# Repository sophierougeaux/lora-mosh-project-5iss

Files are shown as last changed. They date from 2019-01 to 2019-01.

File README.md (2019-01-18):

# LoRa Project: Smart Gas Sensor
> Elie Taillardat & Sophie Rougeaux

##### *Key-words:* ```Arduino``` ```KiCad``` ```The Thing Network``` ```LoRa``` ```Node-RED``` ```IoT``` ```Gas sensor```

This project is realised in the 5th year PTP ISS at INSA Toulouse.
A **LoRa-connected gas sensor** has been developed to alert the user about the concentration of health threatening gas near the sensor.

# Content

This repository contains :
- **KiCad PCB Files**: A shield for the gas sensor to plug on an Arduino Uno (made with [KiCad](http://kicad-pcb.org/))
- **Arduino Code**: The code for the microcontroler (using [Arduino IDE](https://www.arduino.cc/en/Main/Software))

A **Node-RED Dashboard** has been done to stay connected with your sensor. The development of this HMI is described at the end of this Readme. ([Node-RED](https://nodered.org/) and [Freeboard.io](https://freeboard.io/))

## KiCad PCB Files
### Overview
The shield is composed of :
- A home-made gas sensor (made at [AIME](https://www.aime-toulouse.fr/cmsms/index.php))
- An amplifier stage for home-made gas sensor
- A commercial gas sensor for the calibration of the home-made one (Grove connectors)
- A LoRa chip for the data transmission
- A LED as an on/off indicator

> We built our own footprints libraries expect for the Arduino Uno component

### Schematics

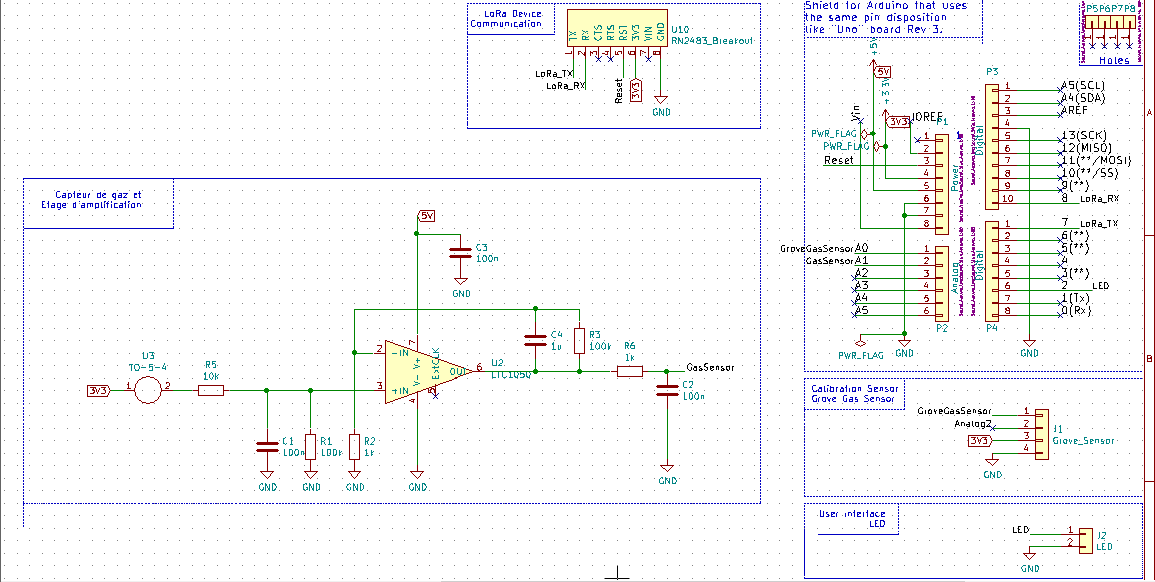
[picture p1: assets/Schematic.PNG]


### PCB Layout

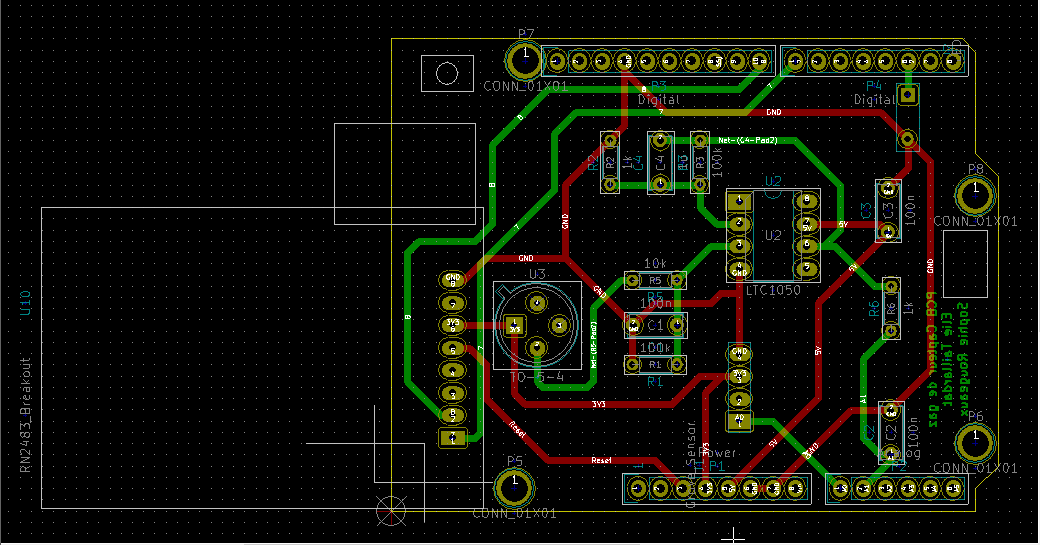
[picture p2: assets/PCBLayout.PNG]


These parameters have been respected to respect the INSA PCB production capacity : 

 - Isolation : 0.4
 - Largeur piste : 0.8
 - Via : 1.6
 - Perçage Via : 0.8

### 3D Visualization

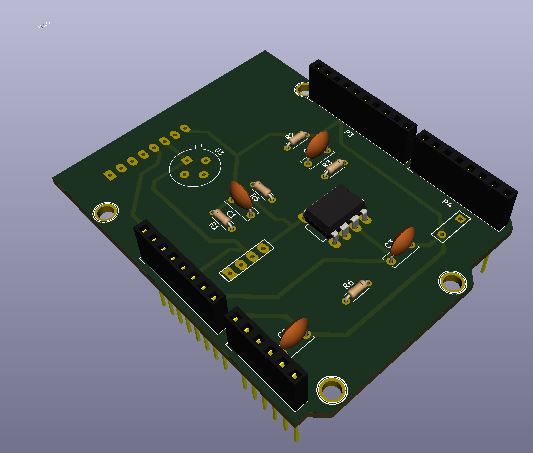
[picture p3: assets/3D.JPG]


## Arduino Board & Code
We have done a **prototype** using a Grove gas sensor to measure the gas concentration in the air.

### Arduino Board
The elements in this project are : 

 - An Arduino Uno
 - A LoRa chip RN2783A
 - A Grove gas sensor (v1.4) MQ-9
 - A LED

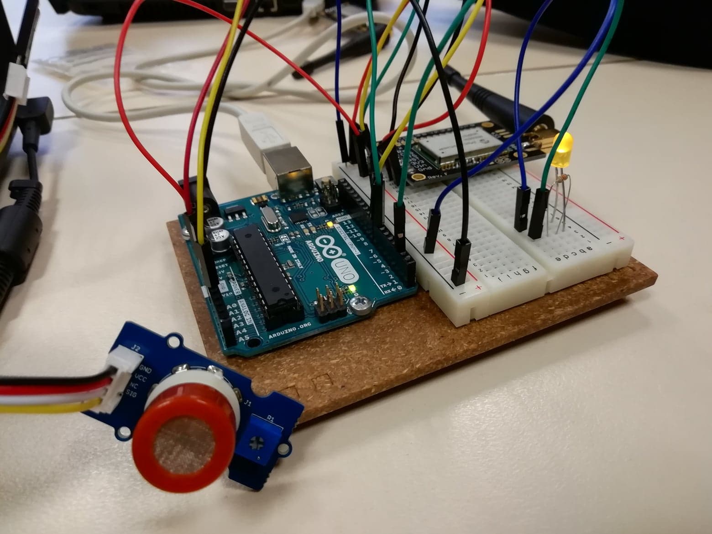
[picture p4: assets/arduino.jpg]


### Overview of the code
Data from a **Grove gas sensor** is transmitted with a **RN2483A chip**, via the **LoRa network**, to a TTN ([The Things Network](https://www.thethingsnetwork.org/)) account in which the Arduino device is registered.
The Arduino listens for incoming messages from a **dashboard** that is linked with the TTN account and allows the user to switch the gas sensor **on and off**.
A **LED** switches on and off according to the gas sensor state.

> You will find more information about the dashboard in the next section

#### Libraries
The communication bewteen the Arduino and the RN2483A is **serial**, so you will need the `SoftwareSerial` library. 
Communication with [The Things Network](https://www.thethingsnetwork.org/) is achieved with the very well written`TheThingsNetwork` library.

#### LoRa setup
To send data to [The Things Network](https://www.thethingsnetwork.org/), you will need to create an account, register your device, and enter your **device IDs** in the Arduino code : 
```c
// Set your AppEUI and AppKey
const char *devAddr = "26011253";
const char *nwkSKey = "D1A126A957FC1C25F20D3DB5379E3DE6";
const char *appSKey = "FC290B61D206CD05073F42CF673DE592";
```
The, the TTN library provides functions to quickly **setup your LoRa chip**, like `personalize(devAddr, nwkSKey, appSKey);`.

#### Sending sensor values
To send data, the function `readAndSend` reads the analog data from the sensor and prepares the **payload** containing the read value in **bytes**. Then, `sendBytes` function from TTN is used to transmit the data.
```c
void readAndSend() {

  // Read sensor
  int sensorValue = analogRead(sensorPin);
  debugSerial.println(sensorValue);

  // Prepare payload
  byte payload[2];
  payload[0] = sensorValue >> 8;
  payload[1] = sensorValue;

  // Send it off
  ttn.sendBytes(payload, sizeof(payload));
}
```
#### Receiving data 
The **callback function** `onMessage` provided by the TTN library listens for an incoming message (**downlink mode** in TTN).
When a message is received, the `message` function is called.

If a `0` is received, the LED switches off and we will **stop** reading the gas sensor values. We will just keep the connection **alive**:
```c
void keepAlive() {

  // Prepare payload (default payload FF)
  byte payload[1];
  payload[0] = 0xFF;

  // Send it off on port 2 to indicate this not a sensor value
  ttn.sendBytes(payload, sizeof(payload), 2);
}
```
When a `1` is received, we switch on the light and we will **start** reading the sensor values using the previsouly presented `readAndSend` function.

## Node-Red Dashboard
### TTN data payload
Data sent by the **Arduino board** through **LoRa network** are decoded thanks to our ```Decoder``` function that we precised in the *Payload Format* section on TTN, which allows to generate an understandable payload with the bytes received, as ```json``` format for instance.
Our ```Decoder``` is presented below:
```javascript
function Decoder(bytes, port) {
  // Decode an uplink message from a buffer
  if (port === 2) { // send via the dashboard to stop gas sensor, see next chapter
    return { waiting: true };
    
  } else if (port === 1) {
    var gas = (bytes[0] << 8) | bytes[1];       // value between 0 and 1024
    var nano = (bytes[2] << 8) | bytes[3];
    
    // transform into readable data
    var gas_volt = gas / 1024 * 5.0;
    var gas_ratio = (5.0 - gas_volt)/gas_volt;  // see datasheet for the calculation
    var R0 = 9.3;                               // sensor resistance at 1000ppm LPG in the clean air
    return {
      gas: (gas_ratio/R0).toFixed(2),
      nano: nano
    };
  }
}
```
> We code the ```nano``` variable in prevision of the future nano-particules sensor that we will design at AIME). For now it is useless.

And the result for a simulated uplink payload on port 1: ``` 02 BE 01 F5 ```
```json
{
  "gas": 7.02,
  "nano": 5.01
}
```

### Node-RED
Once the payload is well interpreted in TTN, we use the tool **Node-RED** built on Node.js, to deal with our data and then display them in a dashboard for user consultation.

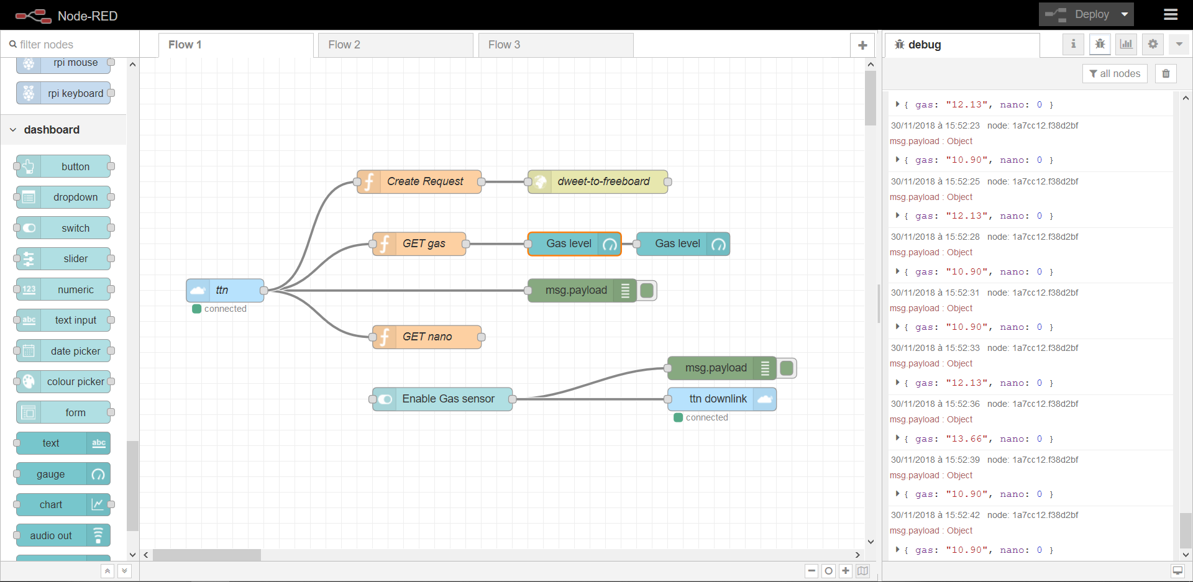
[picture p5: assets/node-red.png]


We use a ``` ttn uplink ``` node linked to our application (```App ID: 20079652```) and registered device (```Device ID: arduino_gaz_sensor```). When a data is received, we can observe in the **debug** console the ```json``` payload received (output of the debug node, cf. picture above in the right panel). Therefore we received the payload as expected.
The dashboard compiled is shown below:

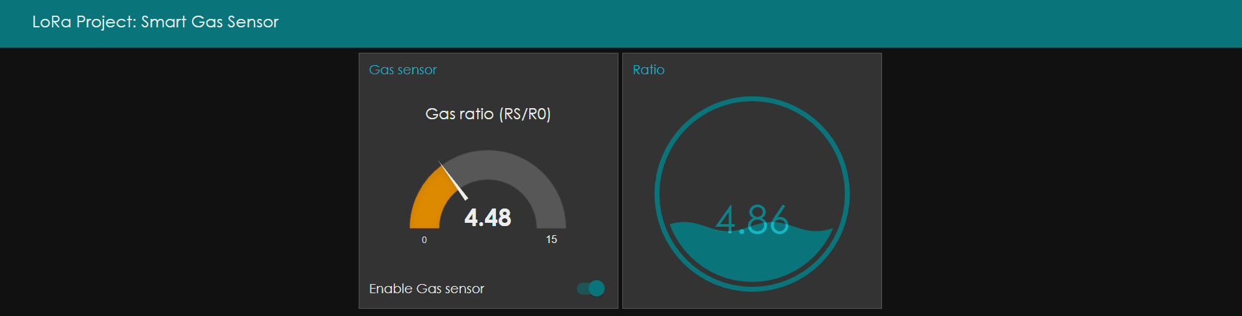
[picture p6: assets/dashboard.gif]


As we can see, **we add a switch to control the state of the gas sensor remotely**.
When switched off for example, the payload sent in the ```ttn downlink``` node looks like:
```json
{
  "gas_sensor": false,
}
```

Then our Encoder on TTN sends to the Arduino board a bytes payload ```00``` or ```01``` (on port 2 or 3):
```javascript
function Encoder(object, port) {
  // Encode downlink messages sent as
  // object to an array or buffer of bytes.
  var bytes = [];
  if (port === 2) bytes[0] = object.gas_sensor ? 1 : 0;
  if (port === 3) bytes[0] = object.nano_sensor ? 2 : 0;

  return bytes;
}
```

When we simulate this behavior in real time, we can see the expected result on the TTN console output, and the LED switched off on our Arduino board:

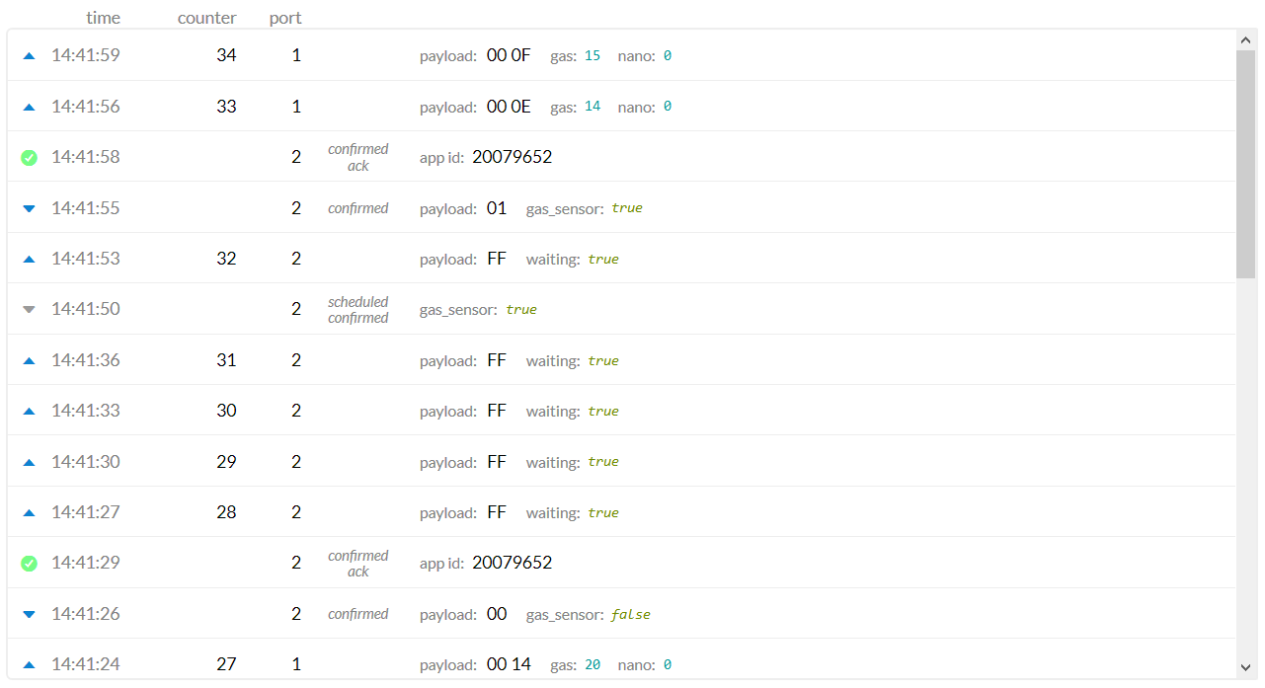
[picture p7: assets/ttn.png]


> Here, we can see that when switched off, the Arduino board stops sending data and is in a *waiting* mode. Once we switched on, the data are sent and received again.

### Freeboard.io
In addition to the localhost Node-RED dashboard we created, we prefered to use also Freeboard.io, to access the interface anywhere, and not only on our laptop localhost (http://127.0.0.1:1880/ui/).
That's the aim of the dweet node, which transfers the payload to a specific **topic**, that we will use in our freeboard dashboard.

**Dashboard link:
https://freeboard.io/board/Wauqxs**

> The curve allows the user to interpret the Gas ratio, and obtain a value in **ppm** of the gas concentration.

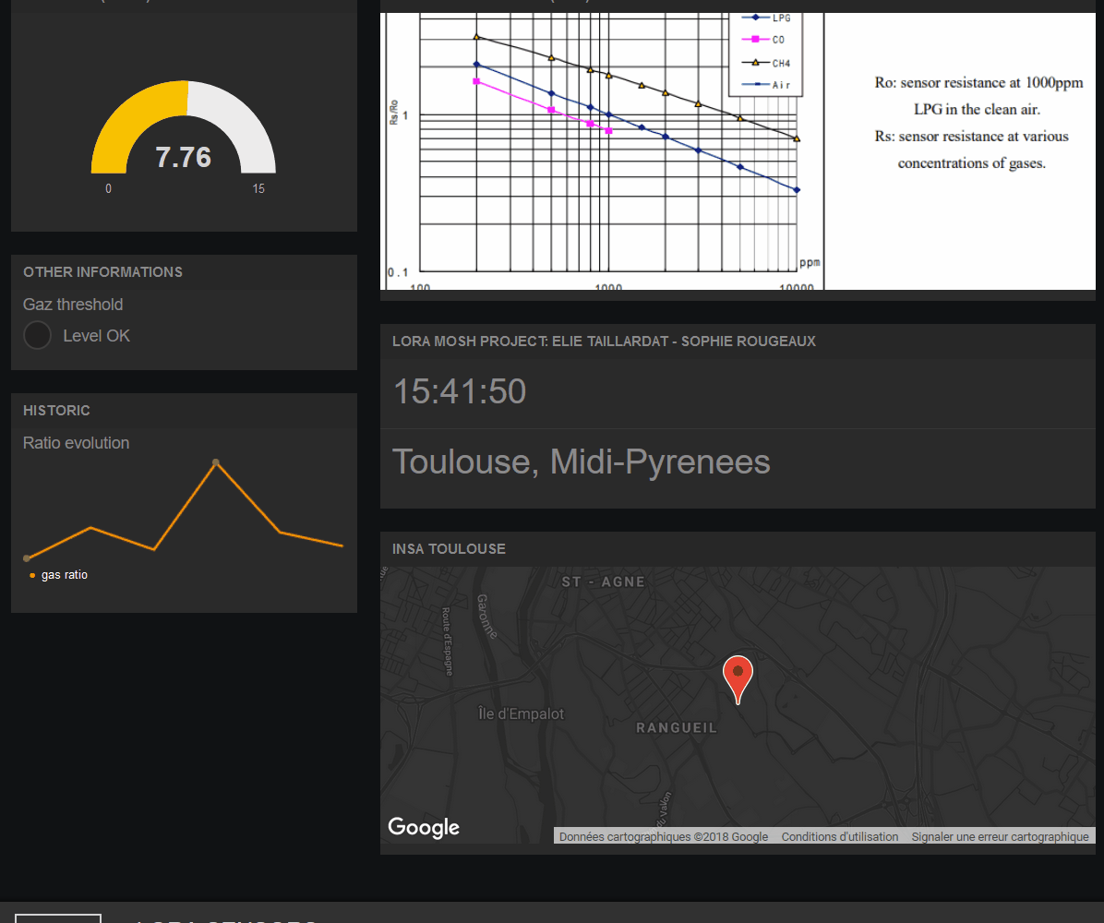
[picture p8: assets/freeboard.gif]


## Contact
- Elie Taillardat: taillard@etud.insa-toulouse.fr
- Sophie Rougeaux: rougeaux@etud.insa-toulouse.fr

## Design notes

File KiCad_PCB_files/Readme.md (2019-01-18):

## KiCad Files
You will find the KiCad project under UNO/UNO.pro

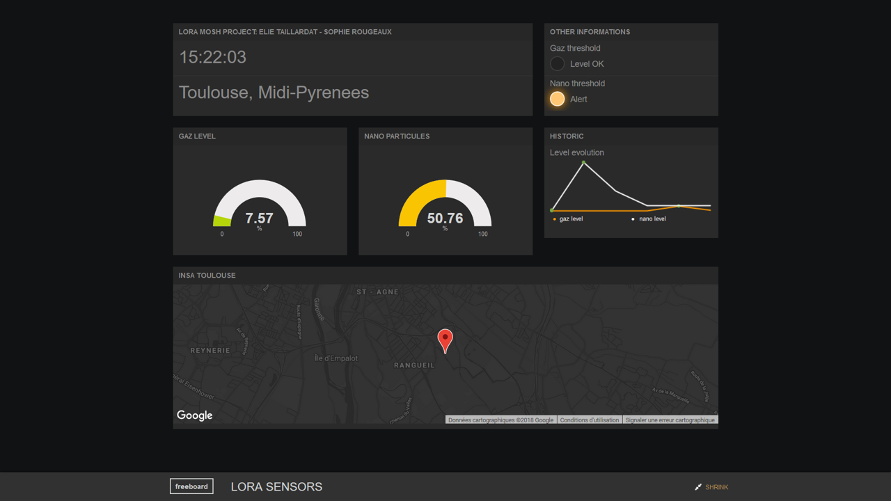
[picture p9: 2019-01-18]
assets/freeboard.png

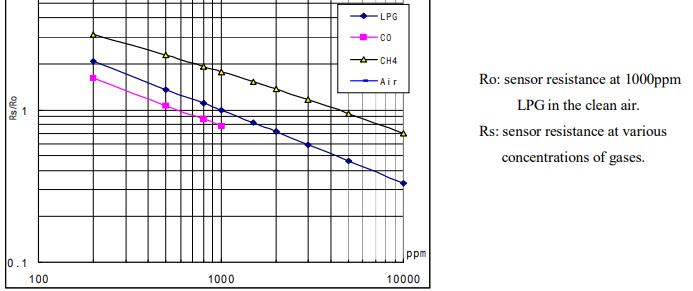
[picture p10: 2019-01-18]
assets/gas_curve.png

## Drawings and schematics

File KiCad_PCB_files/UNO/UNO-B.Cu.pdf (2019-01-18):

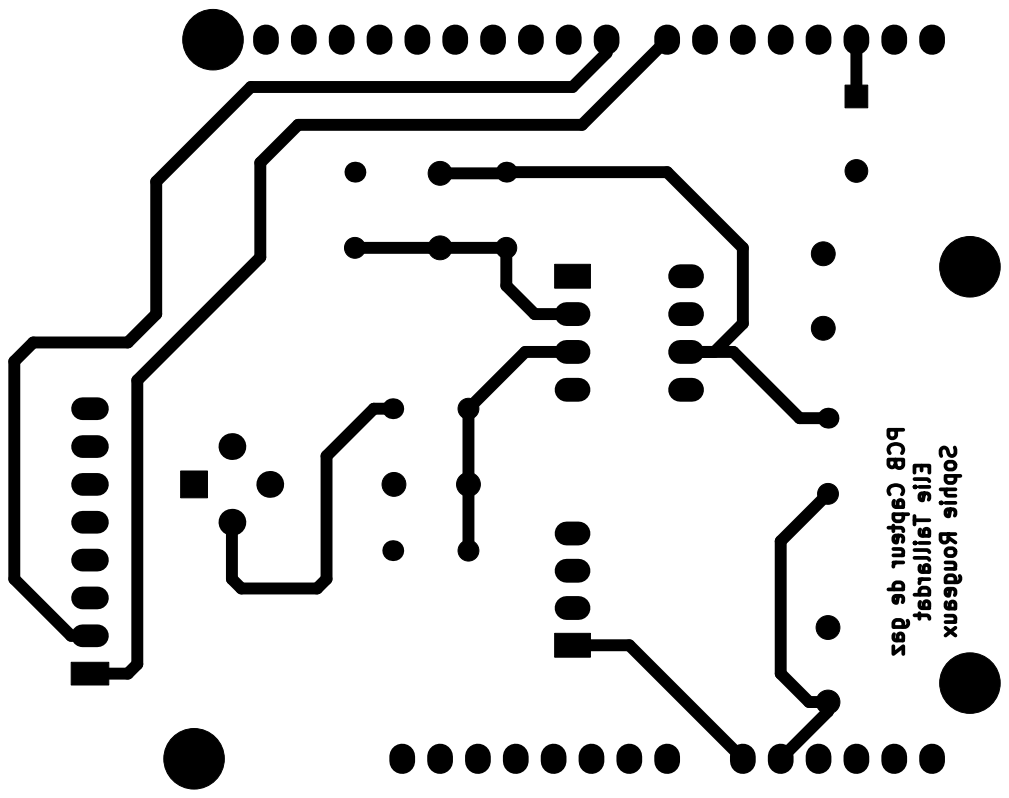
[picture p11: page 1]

PCB Capteur de gaz Elie Taillardat Sophie Rougeaux

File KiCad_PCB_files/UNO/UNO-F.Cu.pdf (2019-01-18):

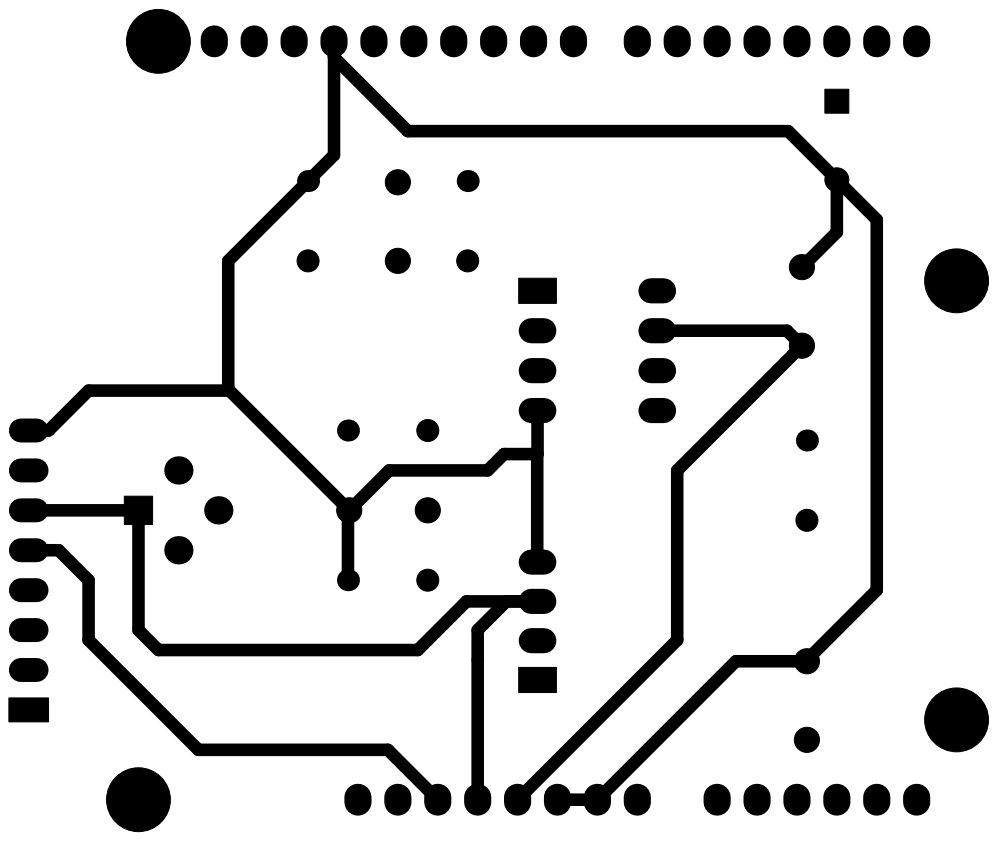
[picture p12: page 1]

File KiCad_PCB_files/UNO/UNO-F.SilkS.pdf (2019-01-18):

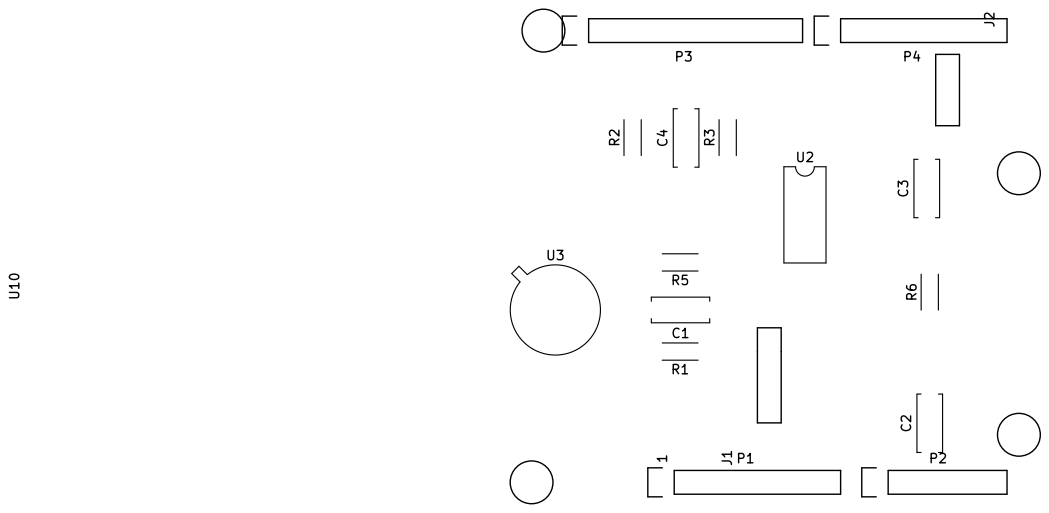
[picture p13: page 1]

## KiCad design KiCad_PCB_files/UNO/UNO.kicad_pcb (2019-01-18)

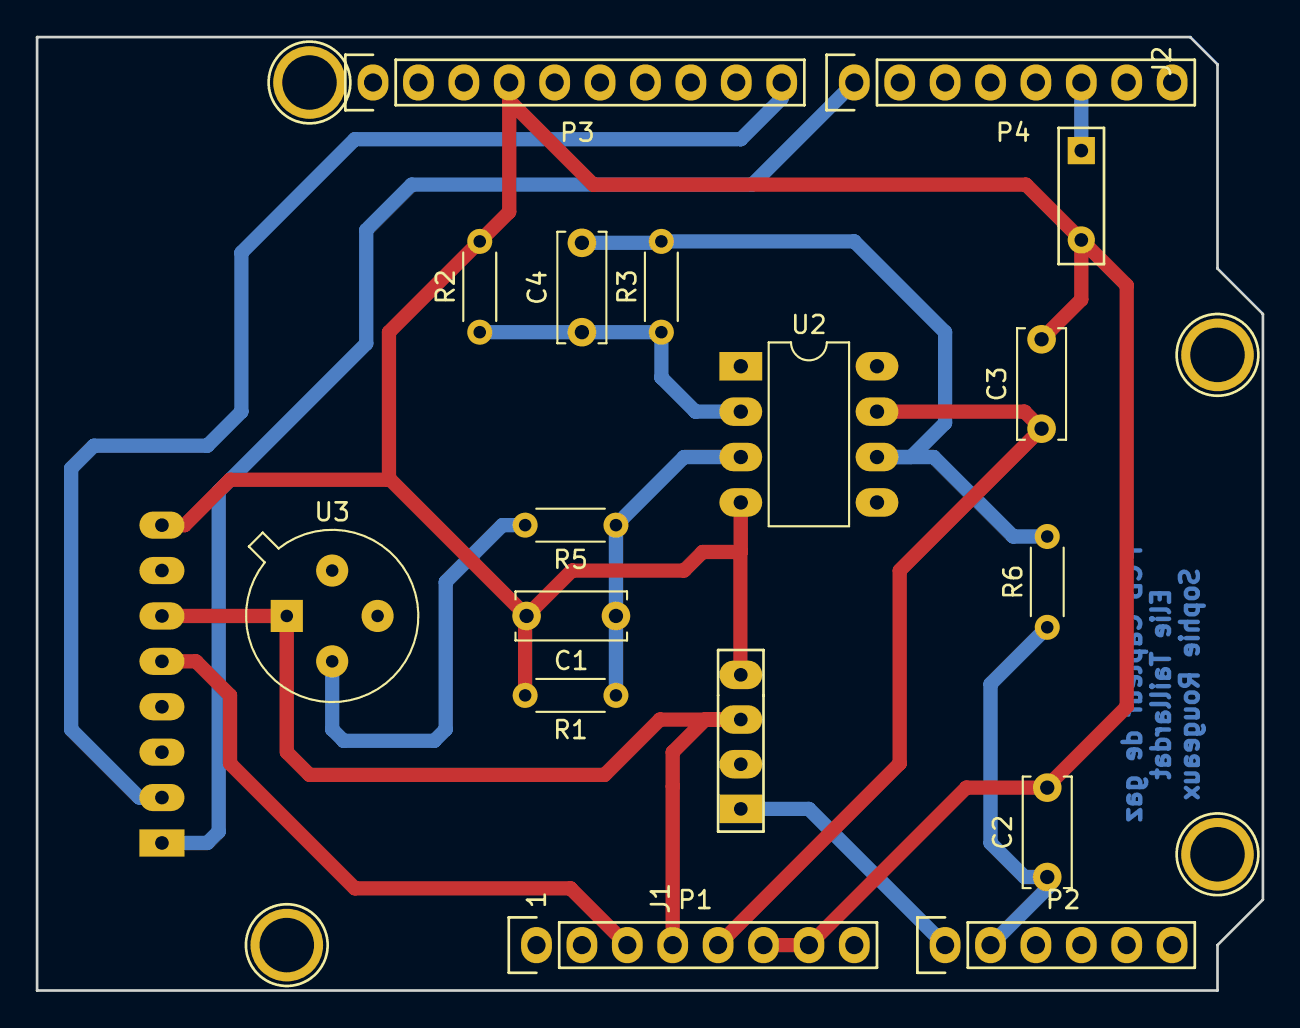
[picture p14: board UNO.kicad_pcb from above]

Board: 2 copper layers, 68.6 x 53.3 mm, 22 parts (0 on the bottom side), 13 nets.

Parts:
C1, C2, C3: 100n; C_Disc_D6.0mm_W2.5mm_P5.00mm
C4: 1u; C_Disc_D6.0mm_W2.5mm_P5.00mm
J1: Grove_Sensor; conn_Grove
J2: LED; conn_LED
P1: Power; Socket_Strip_Arduino_1x08
P2: Analog; Socket_Strip_Arduino_1x06
P3: Digital; Socket_Strip_Arduino_1x10
P4: Digital; Socket_Strip_Arduino_1x08
P5, P6, P7, P8: CONN_01X01; Arduino_1pin
R1, R3: 100k; R_Axial_DIN0204_L3.6mm_D1.6mm_P5.08mm_Horizontal
R2, R6: 1k; R_Axial_DIN0204_L3.6mm_D1.6mm_P5.08mm_Horizontal
R5: 10k; R_Axial_DIN0204_L3.6mm_D1.6mm_P5.08mm_Horizontal
U2: LTC1050; DIP-8_W7.62mm_LongPads
U3: TO-5-4
U10: RN2483_Breakout; Module_RN2483_Breakout_WITHOUTPADS

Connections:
3V3: J1.3, P1.4, U3.1, U10.6
5V: C3.1, P1.5, U2.7
/2: J2.1, P4.6
/7: P4.1, U10.1
/8: P3.10, U10.2
/A0: J1.1, P2.1
/A1: C2.1, P2.2, R6.1
/Reset: P1.3, U10.5
GND: C1.2, C2.2, C3.2, J1.4, J2.2, P1.6, P1.7, P3.4, R1.2, R2.2, U2.4, U10.8
unnamed: C1.1, R1.1, R5.1, U2.3
unnamed: C4.1, R2.1, R3.1, U2.2
unnamed: C4.2, R3.2, R6.2, U2.6
unnamed: R5.2, U3.2

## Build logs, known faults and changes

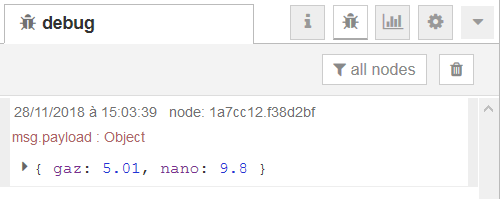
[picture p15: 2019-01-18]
assets/debug-node-red.png

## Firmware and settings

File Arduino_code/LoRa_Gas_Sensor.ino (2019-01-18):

/*
  Arduino Gas Sensor

  The data from a Grove gas sensor is transmitted with a RN2483A chip, via the LoRa network, to a TTN (The Things Network) account in which the Arduino device is registered.
  A dashboard is linked with the TTN account and allows the user to interact with the gas sensor to switch it on and off.
  A LED switches ON when the sensor is read, and OFF when it is not.
  Link for our dashboard : https://freeboard.io/board/Wauqxs
  Note 1 : Data are visible on this dashboard only if the associated NodeRed server is running
  Note 2 : We have also made a local dashboard with NodeRed dashboard

  The circuit:
    RN2483A chip
      TX          <-->     7
      RX          <-->     8
      3V3         <-->     3V3
      GND         <-->     GND

    Grove Gas Sensor (v1.4)
      SIG         <-->     A0
      VCC         <-->     5V
      GND         <-->     GND

    LED           <-->     2

  Created 30 november 2018
  By Sophie Rougeaux & Elie Taillardat
  In the context of the Innovative Smart Systems PTP - INSA Toulouse

  Project available on GitHub : https://github.com/elietaillardat/lora-mosh-project-5iss

*/

#include <SoftwareSerial.h>
#include <TheThingsNetwork.h>

// Set your AppEUI and AppKey
const char *devAddr = "26011253";
const char *nwkSKey = "D1A126A957FC1C25F20D3DB5379E3DE6";
const char *appSKey = "FC290B61D206CD05073F42CF673DE592";

// Pins
int sensorPin = A0;
#define LED_PIN           2
#define TX_PIN            7   //RN2483A TX pin
#define RX_PIN            8   //RN2483A RX pin

// Variables
bool ONreceived = true;
#define debugSerial Serial
SoftwareSerial loraSerial(TX_PIN, RX_PIN); //Serial link with the LoRa module
#define freqPlan TTN_FP_EU868              // Choose TTN_FP_EU868 (Europe) or TTN_FP_US915 (United States)

TheThingsNetwork ttn(loraSerial, debugSerial, freqPlan);

/*
   SETUP
*/

void setup()
{
  loraSerial.begin(57600);
  debugSerial.begin(9600);

  // Wait a maximum of 10s for Serial Monitor
  while (!debugSerial && millis() < 10000)
    ;

  // Set callback for incoming messages
  ttn.onMessage(message);

  // Configure RN2483A using The Things Network library
  debugSerial.println("-- PERSONNALIZE");
  ttn.personalize(devAddr, nwkSKey, appSKey);

  debugSerial.println("-- STATUS");
  ttn.showStatus();

  pinMode(sensorPin, INPUT);
  pinMode(LED_PIN, OUTPUT);

  digitalWrite(LED_PIN, HIGH);

}


/*
   LOOP
*/


void loop()
{
  debugSerial.println("-- LOOP");

  // If the user activated the sensor on the web plateform, switch the led on, read the sensor value and send the data
  // Else, switch the led off and keep the connection alive

  if (ONreceived) {
    readAndSend();
  } else {
    keepAlive();
  }
  
  delay(500);
}


/*
   FUNCTIONS
*/


/*
   Reads the sensor value and sends it to the Things Network
*/

void readAndSend() {

  // Read sensor
  int sensorValue = analogRead(sensorPin);
  debugSerial.println(sensorValue);

  // Prepare payload
  byte payload[2];
  payload[0] = sensorValue >> 8;
  payload[1] = sensorValue;

  // Send it off
  ttn.sendBytes(payload, sizeof(payload));
}

/*
   Keeps the connection alive by sending a non-meanigful payload
*/

void keepAlive() {

  // Prepare payload (default payload FF)
  byte payload[1];
  payload[0] = 0xFF;

  // Send it off on port 2 to indicate this not a sensor value
  ttn.sendBytes(payload, sizeof(payload), 2);
}


/*
    Receives 1-byte messages
    Activates or desactivates the sensor with the boolean ONreceived and switches the LED states accordingly
*/

void message(const byte *payload, size_t length, port_t port)
{
  debugSerial.println("-- MESSAGE");

  // Only handle messages of a single byte
  if (length != 1) {
    return;
  }

  if (payload[0] == 0)
  {
    debugSerial.println("received: off");
    ONreceived = false;
    digitalWrite(LED_PIN, LOW);
    delay(1000);
  }
  else if (payload[0] == 1)
  {
    debugSerial.println("received: on");
    ONreceived = true;
    digitalWrite(LED_PIN, HIGH);
    delay(1000);
  }
}
